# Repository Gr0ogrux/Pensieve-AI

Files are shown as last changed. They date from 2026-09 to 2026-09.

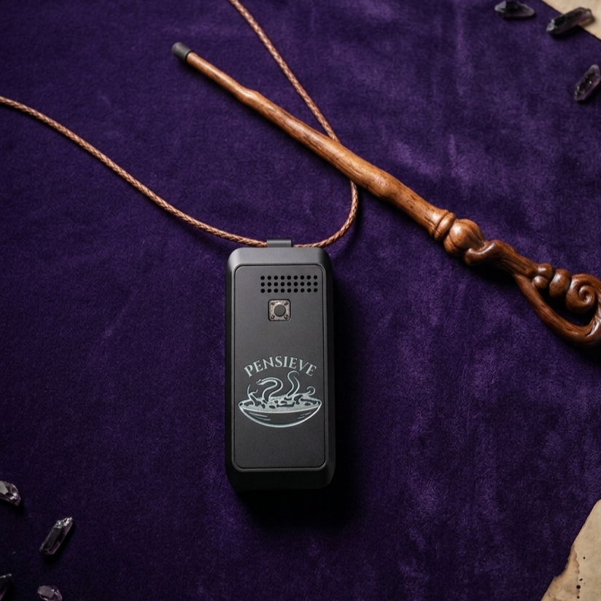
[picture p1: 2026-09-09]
images/pensieve_device.png

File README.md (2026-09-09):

pensieve_device

# **Pensieve AI** — a wearable voice assistant built from scratch

A push-to-talk pendant that records what you say, transcribes it locally,
figures out whether it's a reminder, calendar event, or just a note, and
files it into Google Calendar / Tasks automatically - no phone app, no
subscription, no cloud company's assistant, just a $30-ish pile of parts
and open firmware.

Press the button, say something, let go. That's the entire interaction.

## What it actually does

1. Records while the button is held (up to 60s), then stops
2. Saves to a microSD card - recordings are never lost even with no WiFi
3. Opportunistically syncs over WiFi whenever it's in range (on button
   press, or automatically once an hour even if you haven't used it)
4. A receiver script on a PC transcribes the audio locally (private,
   free - no audio ever leaves your network)
5. A small AI call classifies the transcript into an event / task / note
   and extracts the relevant details (dates, times, titles)
6. That gets pushed straight into Google Calendar or Google Tasks
7. Runs in deep sleep between uses for real multi-day battery life

## Why build this instead of buying one

Commercial AI pendants exist (Bee, Fieldy, etc.) but they're subscription
products with someone else's cloud in the middle. This is the same idea,
built from parts you can buy today, with the audio-to-transcript step
happening entirely on your own hardware, and the code fully open so you
can see (and change) exactly what it's doing with what you say.

## Hardware

| Part | Notes |
|---|---|
| Seeed XIAO ESP32-S3 Sense | The board - has the mic, camera (unused here), and microSD slot built in |
| LiPo battery, 3.7V, ~1000mAh, JST-PH1.25 connector | Solders directly to the board's BAT+/BAT- pads (no connector on the board itself) |
| Momentary tactile push button | 6x6mm style, 4-leg (2 electrical pairs) |
| 4x 4mm x 1mm neodymium magnets | Holds the case closed |
| Necklace cord | Threads through the printed bail |
| A 3D printer | PETG recommended for the final print, PLA fine for test-fitting |

Total cost is roughly $25-35 depending on where you source parts.

## Repo structure

- **`firmware/`** — the Arduino sketch that runs on the pendant itself
- **`case/`** — the 3D-printable case (parametric OpenSCAD source + ready-to-print STLs)
- **`server/`** — the Python script that runs on a PC, receives recordings, transcribes and classifies them, and creates the Calendar/Tasks entries
- **`docs/`** — supplementary notes (wiring, troubleshooting)

Each folder has its own README with setup specifics.

## Quick start

1. **Print the case** — see `case/README.md`
2. **Wire the button and battery** — see `docs/WIRING.md`
3. **Flash the firmware** — see `firmware/README.md`
4. **Set up the receiver** — see `server/README.md` (this is the more
   involved part: Python environment, a free Google Cloud project for
   Calendar/Tasks access, and a Gemini API key)
5. Press the button, say something, check your Google Tasks a few
   seconds later

## Known limitations / honest caveats

- **Battery life is genuinely limited by the ESP32-S3's always-on idle
  draw** if you don't use the deep-sleep firmware — expect closer to
  "charge nightly like a phone" than "charge weekly." The deep-sleep
  version in this repo addresses this, at the cost of a small delay
  (and possible clipped first syllable) each time you press the button,
  since the chip does a real reboot on every wake.
- **The XIAO ESP32-S3 has no dedicated JST battery connector** — only
  bare solder pads. Soldering directly to a LiPo is genuinely more
  dangerous than a plug-in connector; read `docs/WIRING.md` before
  attempting it.
- **This was built and debugged interactively over a single very long
  session**, including working through several real hardware/firmware
  interaction bugs (documented in `docs/` for anyone hitting the same
  walls). It works, but it's a hobbyist build, not a polished product.

## License

MIT — do whatever you want with this, attribution appreciated but not required.

---

*This project's code — firmware, case design, and server — was developed
with assistance from Google Gemini and Anthropic Claude.*

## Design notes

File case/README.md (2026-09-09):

# 3D Printed Case

`Pensieve AI.stl` is the ready-to-print export of the current wearable enclosure design, modeled in Tinkercad[cite: 1, 2].

## Design

- **Integrated alignment system:** Uses locating pins on the lid and mating holes on the base to ensure both halves line up squarely every time it snaps shut.
- **Magnetic latching:** Held closed with 3mm x 1mm neodymium disc magnets instead of screws, making battery checks and microSD access completely toolless[cite: 2].
- **Wearable bail:** Includes a solid integrated loop at the top end for a necklace cord or lanyard, keeping the pendant oriented face-forward rather than flipping around while worn[cite: 2].
- **Dedicated internal compartments:** An internal divider separates the board assembly from the battery compartment, holding each component securely to prevent internal rattles[cite: 2].
- **Acoustic and control cutouts:** Features an acoustic port aligned with the Sense daughterboard's PDM MEMS microphone capsule and dedicated clearances for the push button and USB-C port[cite: 2].

## Before printing

**Check your component dimensions first[cite: 2].** This enclosure was designed specifically around:
- Seeed Studio XIAO ESP32-S3 Sense[cite: 2]
- MakerHawk 803040 LiPo battery[cite: 2]
- 6x6mm tactile push button[cite: 2]
- 3mm x 1mm neodymium disc magnets

Tolerances are tuned around these specific physical parts[cite: 2]. If you use a different battery size or button style, you may need to import the STL into your CAD software to tweak internal clearances.

**Dry-fit everything before final assembly[cite: 2].** Test-fit the stacked XIAO board, battery, button, and magnets inside the shell[cite: 2]. Running a quick test print before final assembly ensures your printer’s calibration and shrinkage rates match the designed tolerances[cite: 2].

## Recommended print settings

- **Material:** PETG for the daily wearable version (more durable and temperature-resistant for everyday carry); PLA works well for rapid test prints[cite: 2].
- **Layer height:** 0.16–0.20 mm[cite: 2].
- **Walls / Perimeters:** 3 perimeters minimum (keeps the shell rigid under pocket or pendant use)[cite: 2].
- **Infill:** 15–20% (Gyroid or Grid)[cite: 2].
- **Supports:** None needed when oriented with the flat surfaces against the build plate[cite: 2].
- **Tolerances note:** PETG flows and flexes slightly differently than PLA, so test your pin-and-hole friction fit and magnet pockets after cooling[cite: 2].

## Magnet polarity

The STL file cannot encode magnet polarity[cite: 2]. Before applying superglue or epoxy into the magnet pockets, place a base magnet and lid magnet together to verify attraction[cite: 2]. If they repel, flip one side over before setting them into the recesses[cite: 2].

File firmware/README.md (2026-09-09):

# Firmware

`xiao_pendant_pushtotalk.ino` — the deep-sleep, push-to-talk version.
This is what actually runs on the pendant.

## Board setup (Arduino IDE)

1. Install the **"esp32" board package by Espressif Systems** via
   Boards Manager (not "Arduino ESP32 Boards" — there are two similarly
   named packages, you want Espressif's).
2. Select **Tools > Board > XIAO_ESP32S3**
3. Set **Tools > PSRAM > Enabled** (or "OPI PSRAM" depending on your
   core version) — required, the recording buffer lives in PSRAM
4. Upload speed of 921600 is fine (the default for this board)

## Before uploading

Open the sketch and fill in these three lines near the top:

```cpp
const char* WIFI_SSID     = "YOUR_WIFI_NAME";
const char* WIFI_PASSWORD = "YOUR_WIFI_PASSWORD";
const char* SERVER_URL    = "http://YOUR_PC_LOCAL_IP:5000/upload";
```

`SERVER_URL` is the local IP address of whichever PC is running the
receiver script (see `../server/`), found via `ipconfig` (Windows) or
`ifconfig`/`ip addr` (Mac/Linux). It has to be the PC's IP on your
*local* network (e.g. `192.168.1.x`), not a public address.

## How it behaves

- Press and hold the button (wired to pin D0) to record, release to stop
- Recordings longer than 60 seconds are automatically cut off (safety cap)
- Presses shorter than ~0.5s are discarded as accidental taps
- After recording, it tries to sync over WiFi (10s timeout) — if no
  WiFi is in range, the file just waits on the SD card and gets picked
  up on the next successful sync
- It also wakes up on its own once an hour to try syncing even without
  a button press
- Files that fail to upload twice are deleted automatically (almost
  always an accidental/garbage recording, not something worth
  retrying forever)
- Synced recordings are archived on the SD card and auto-deleted after
  7 days (configurable via `SENT_FILE_RETENTION_DAYS`)

## The deep sleep tradeoff (read this before you're confused by it)

This version puts the chip into deep sleep between actions rather than
staying fully awake — this is what gets you multi-day battery life
instead of roughly one day. The tradeoff: deep sleep is closer to a
full reboot than a pause. Every time it wakes (button press or hourly
timer), it's genuinely re-running `setup()` from scratch. That costs a
small delay before recording can start, and it's possible for the very
first instant of speech to be clipped while the mic finishes
initializing. If that's more annoying in practice than the battery
life is worth to you, an always-on (no deep sleep) version is a much
simpler modification — remove the `goToSleep()` call and the wake-cause
branching in `setup()`, and let `loop()` poll the button directly instead.

## Timezone

The NTP time sync (used for tracking how old archived files are)
defaults to US Eastern (`EST5EDT,M3.2.0,M11.1.0`). If you're elsewhere,
change the `TZ_STRING` constant — search "POSIX TZ string" for your
region's format.

## Wiring

See `../docs/WIRING.md` for the button and battery connections.

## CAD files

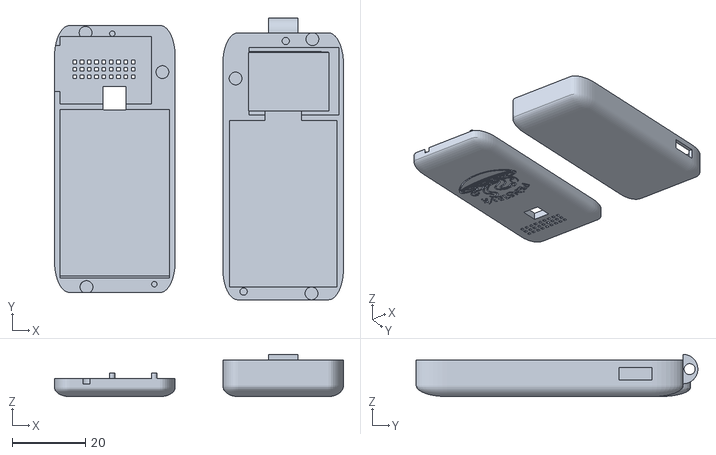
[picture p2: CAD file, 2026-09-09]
case/Pensieve AI.stl
79.0 x 77.0 x 11.5

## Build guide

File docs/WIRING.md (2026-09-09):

# Wiring

## Button

Wire one leg of the button to pin **D0** on the XIAO board, and the
other leg to any **GND** pin. No resistor needed — the firmware uses
the board's internal pull-up resistor.

Most small tactile buttons have 4 legs that are really just 2
electrical pairs (diagonal legs are connected to each other internally).
You only need one leg from each pair — check with a multimeter's
continuity mode if you're not sure which legs pair together.

## Battery

**The XIAO ESP32-S3 does not have a battery connector** — only two bare
solder pads on the underside of the board, labeled **BAT+** and
**BAT-** (small text, use a magnifying glass or your phone's camera
zoomed in to confirm you're reading them correctly).

This means either:
- Soldering a matching connector onto the pads (if your battery has a
  detachable connector and you have a matching part), or
- Soldering the battery's wires directly to the pads (permanent, but
  requires no extra parts)

### If soldering directly to the pads

This involves a LiPo battery, which is less forgiving of mistakes than
low-voltage signal wiring. A few things that matter here specifically,
not just generally good soldering practice:

1. **Identify polarity carefully.** Red is conventionally positive and
   black negative, but verify with a multimeter if you have one rather
   than assuming.
2. **If you need to cut the battery's existing wires** (e.g. to remove
   a connector that doesn't match anything you have), cut ONE wire at
   a time, not both together — cutting both simultaneously with a tool
   that spans both risks momentarily bridging positive and negative
   through the metal cutters, which is a real short-circuit risk on a
   LiPo cell.
3. **Double-check polarity again immediately before soldering** —
   positive wire to the pad marked +, negative to the pad marked -.
   Reversed polarity here can damage the board's charging circuit or
   the battery itself.
4. **Insulate both joints completely** (heat-shrink tubing or
   electrical tape) before final assembly — these joints will sit close
   to other components inside a sealed case, and an exposed short on a
   LiPo connection is a genuine fire/damage risk, not just "it won't work."
5. **Test power-up somewhere you can watch it** for the first minute or
   two (not inside the sealed case yet) — check for any unusual heat,
   smell, or the charge LED behaving normally.

Note: soldering directly to the pads means there's no way to fully
power the board off short of physically disconnecting a wire — it's
always live as long as the battery's connected. Not dangerous, just
worth knowing (the board will slowly drain the battery even sitting
idle, so give it an occasional charge if it goes unused for a while).

### Charging

Check your specific board's actual charge current before assuming a
number — it's been inconsistently documented in different places
(Seeed's wiki and datasheet have listed different figures for the same
board). At a conservative 50mA, a 1000mAh battery takes roughly 20-24
hours for a full charge from empty; budget accordingly rather than
expecting a quick top-up.

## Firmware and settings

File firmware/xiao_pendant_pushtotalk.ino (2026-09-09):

/*
 * XIAO ESP32-S3 Sense — "AI Pendant" recorder, DEEP SLEEP version
 *
 * Press and hold the button to record, release to stop (up to
 * MAX_RECORD_SECS as a safety cap). Between uses, the chip is in deep
 * sleep -- the lowest-power state available -- rather than sitting
 * fully awake waiting for a button press. It wakes on either:
 *   - the button being pressed, or
 *   - an hourly timer, to opportunistically sync over WiFi even if
 *     the button hasn't been touched
 *
 * IMPORTANT BEHAVIOR CHANGE FROM THE ALWAYS-ON VERSION:
 * Deep sleep is closer to a full power-off than a pause. Every wake
 * is a real reboot -- setup() runs again from scratch each time,
 * re-initializing the mic, SD card, etc. This costs a small amount of
 * time (typically a few hundred ms) before recording can actually
 * start, meaning the very first instant of speech right as you press
 * the button could be clipped while the chip finishes waking up. This
 * is the real tradeoff for the big battery life improvement -- worth
 * being aware of when you test it.
 *
 * WIRING: one leg of the button to pin D0, the other leg to any GND
 * pin on the board. No resistor needed -- we use the internal pull-up
 * (reconfigured for the RTC domain specifically before each sleep, so
 * it holds reliably while the chip is off).
 *
 * BEFORE UPLOADING:
 *   1. Fill in WIFI_SSID, WIFI_PASSWORD, SERVER_URL below.
 *   2. Tools > PSRAM > Enabled
 *   3. Tools > Board > XIAO_ESP32S3 (board package 2.0.14)
 */

#include "driver/i2s.h"
#include "driver/rtc_io.h"
#include "FS.h"
#include "SD.h"
#include <WiFi.h>
#include <HTTPClient.h>
#include "time.h"
#include "esp_sleep.h"

// ---- FILL THESE IN ----
const char* WIFI_SSID     = "YOUR_WIFI_NAME";
const char* WIFI_PASSWORD = "YOUR_WIFI_PASSWORD";
const char* SERVER_URL    = "http://YOUR_PC_LOCAL_IP:5000/upload"; // e.g. http://192.168.1.50:5000/upload
// ------------------------

#define SD_CS_PIN       21
#define I2S_MIC_CLK     42
#define I2S_MIC_DATA    41
#define SAMPLE_RATE     16000
#define MAX_RECORD_SECS 60      // safety cap -- recording stops here even if button stays held
#define I2S_PORT        I2S_NUM_0
#define BUTTON_PIN      1       // D0 on the XIAO -- other leg of button goes to GND -- confirmed RTC-capable on ESP32-S3
#define WIFI_TIMEOUT_MS 10000

// ---- Periodic sync + retention settings ----
const int SYNC_INTERVAL_SEC = 3600;               // wake on its own to sync at least this often
const int SENT_FILE_RETENTION_DAYS = 7;           // auto-delete archived recordings older than this
const int MAX_UPLOAD_ATTEMPTS = 2;                // give up and delete after this many failures --
                                                    // almost always an accidental button tap

// ---- NTP time (the board has no real-time clock of its own -- this is
// fetched over the network each time WiFi connects, so file ages can be
// tracked in real calendar days rather than just relative uptime) ----
const char* NTP_SERVER = "pool.ntp.org";
const char* TZ_STRING = "EST5EDT,M3.2.0,M11.1.0"; // US Eastern, handles DST automatically
bool g_timeIsValid = false;

// Survives deep sleep (unlike normal variables) -- purely a diagnostic
// counter so the Serial log shows how many wake cycles have happened.
RTC_DATA_ATTR int bootCount = 0;

uint8_t *g_fileBuf = nullptr;
const uint32_t MAX_SAMPLES = SAMPLE_RATE * MAX_RECORD_SECS;

void writeWavHeaderToBuf(uint8_t *header, uint32_t dataSize, uint32_t sampleRate) {
  uint32_t totalDataLen = dataSize + 36;
  uint32_t byteRate = sampleRate * 1 * sizeof(int16_t);
  header[0]='R'; header[1]='I'; header[2]='F'; header[3]='F';
  header[4]=(byte)(totalDataLen); header[5]=(byte)(totalDataLen>>8);
  header[6]=(byte)(totalDataLen>>16); header[7]=(byte)(totalDataLen>>24);
  header[8]='W'; header[9]='A'; header[10]='V'; header[11]='E';
  header[12]='f'; header[13]='m'; header[14]='t'; header[15]=' ';
  header[16]=16; header[17]=0; header[18]=0; header[19]=0;
  header[20]=1; header[21]=0;
  header[22]=1; header[23]=0;
  header[24]=(byte)(sampleRate); header[25]=(byte)(sampleRate>>8);
  header[26]=(byte)(sampleRate>>16); header[27]=(byte)(sampleRate>>24);
  header[28]=(byte)(byteRate); header[29]=(byte)(byteRate>>8);
  header[30]=(byte)(byteRate>>16); header[31]=(byte)(byteRate>>24);
  header[32]=2; header[33]=0;
  header[34]=16; header[35]=0;
  header[36]='d'; header[37]='a'; header[38]='t'; header[39]='a';
  header[40]=(byte)(dataSize); header[41]=(byte)(dataSize>>8);
  header[42]=(byte)(dataSize>>16); header[43]=(byte)(dataSize>>24);
}

uint32_t getNextCounter() {
  uint32_t n = 1;
  if (SD.exists("/counter.txt")) {
    File f = SD.open("/counter.txt", FILE_READ);
    if (f) { n = f.parseInt(); f.close(); }
  }
  File f = SD.open("/counter.txt", FILE_WRITE);
  if (f) { f.print(n + 1); f.close(); }
  return n;
}

bool uploadFile(const char* path) {
  File f = SD.open(path, FILE_READ);
  if (!f) return false;
  size_t size = f.size();
  uint8_t *buf = (uint8_t*) ps_malloc(size);
  if (!buf) { f.close(); return false; }
  f.read(buf, size);
  f.close();

  HTTPClient http;
  http.begin(SERVER_URL);
  http.setTimeout(20000);
  http.addHeader("Content-Type", "audio/wav");
  int code = http.POST(buf, size);
  free(buf);
  http.end();

  Serial.printf("  Upload %s -> HTTP %d\n", path, code);
  delay(300);
  return (code == 200);
}

bool syncNTPTime() {
  configTzTime(TZ_STRING, NTP_SERVER);
  struct tm timeinfo;
  if (getLocalTime(&timeinfo, 5000)) {
    Serial.printf("[+] Time synced: %04d-%02d-%02d %02d:%02d:%02d\n",
      timeinfo.tm_year + 1900, timeinfo.tm_mon + 1, timeinfo.tm_mday,
      timeinfo.tm_hour, timeinfo.tm_min, timeinfo.tm_sec);
    return true;
  }
  Serial.println("[!] NTP time sync failed -- skipping file-age cleanup this round.");
  return false;
}

void cleanupOldSentFiles() {
  if (!g_timeIsValid) return;

  time_t now = time(nullptr);
  const time_t maxAgeSecs = (time_t)SENT_FILE_RETENTION_DAYS * 24UL * 3600UL;

  File dir = SD.open("/recordings/sent");
  if (!dir) return;
  File entry;
  while ((entry = dir.openNextFile())) {
    if (!entry.isDirectory()) {
      String name = entry.name();
      entry.close();
      int sep = name.indexOf('_');
      if (sep > 0) {
        String epochStr = name.substring(0, sep);
        bool allDigits = epochStr.length() > 0;
        for (unsigned int i = 0; i < epochStr.length(); i++) {
          if (!isDigit(epochStr[i])) { allDigits = false; break; }
        }
        if (allDigits) {
          time_t fileTime = (time_t) epochStr.toInt();
          if (now - fileTime > maxAgeSecs) {
            String fullPath = String("/recordings/sent/") + name;
            if (SD.remove(fullPath)) {
              Serial.printf("[*] Deleted old archived file (%.1f days old): %s\n",
                (now - fileTime) / 86400.0, name.c_str());
            }
          }
        }
      }
    } else {
      entry.close();
    }
  }
  dir.close();
}

void syncPendingRecordings() {
  File dir = SD.open("/recordings");
  if (!dir) return;
  File entry;
  while ((entry = dir.openNextFile())) {
    if (!entry.isDirectory()) {
      String name = entry.name();
      String fullPath = String("/recordings/") + name;
      entry.close();

      int priorFailures = 0;
      int failMarker = name.indexOf("__fail");
      if (failMarker >= 0) {
        int dotPos = name.indexOf('.', failMarker);
        String countStr = name.substring(failMarker + 6, dotPos > 0 ? dotPos : name.length());
        priorFailures = countStr.toInt();
      }

      Serial.printf("[*] Syncing pending file: %s (prior failures: %d)\n", fullPath.c_str(), priorFailures);

      if (uploadFile(fullPath.c_str())) {
        String sentPath;
        if (g_timeIsValid) {
          sentPath = String("/recordings/sent/") + String((unsigned long)time(nullptr)) + "_" + name;
        } else {
          sentPath = String("/recordings/sent/") + name;
        }
        if (SD.rename(fullPath, sentPath)) {
          Serial.println("  -> uploaded and archived.");
        } else {
          Serial.println("  -> uploaded OK, but archiving failed. Removing local copy to prevent a duplicate re-upload.");
          SD.remove(fullPath);
        }
      } else {
        int newFailCount = priorFailures + 1;
        if (newFailCount >= MAX_UPLOAD_ATTEMPTS) {
          Serial.printf("  -> upload failed %d time(s), giving up and deleting.\n", newFailCount);
          SD.remove(fullPath);
        } else {
          String baseName = (failMarker >= 0) ? name.substring(0, failMarker) : name;
          String stem, ext;
          int dotIdx = baseName.lastIndexOf('.');
          if (dotIdx >= 0) {
            stem = baseName.substring(0, dotIdx);
            ext = baseName.substring(dotIdx);
          } else {
            stem = baseName;
            ext = "";
          }
          String newPath = String("/recordings/") + stem + "__fail" + String(newFailCount) + ext;
          SD.rename(fullPath, newPath);
          Serial.printf("  -> upload failed (attempt %d of %d), will retry next time.\n", newFailCount, MAX_UPLOAD_ATTEMPTS);
        }
      }
    } else {
      entry.close();
    }
  }
  dir.close();
}

bool initI2S() {
  i2s_config_t i2s_config = {
    .mode = (i2s_mode_t)(I2S_MODE_MASTER | I2S_MODE_RX | I2S_MODE_PDM),
    .sample_rate = SAMPLE_RATE,
    .bits_per_sample = I2S_BITS_PER_SAMPLE_16BIT,
    .channel_format = I2S_CHANNEL_FMT_ONLY_LEFT,
    .communication_format = I2S_COMM_FORMAT_STAND_I2S,
    .intr_alloc_flags = ESP_INTR_FLAG_LEVEL1,
    .dma_buf_count = 8,
    .dma_buf_len = 1024,
    .use_apll = false,
    .tx_desc_auto_clear = false,
    .fixed_mclk = 0
  };
  i2s_pin_config_t pin_config = {
    .bck_io_num = I2S_PIN_NO_CHANGE,
    .ws_io_num = I2S_MIC_CLK,
    .data_out_num = I2S_PIN_NO_CHANGE,
    .data_in_num = I2S_MIC_DATA
  };
  return (i2s_driver_install(I2S_PORT, &i2s_config, 0, NULL) == ESP_OK &&
          i2s_set_pin(I2S_PORT, &pin_config) == ESP_OK);
}

// Handles a full sync cycle: connects to WiFi, syncs real time via
// NTP, uploads anything pending, cleans up old archived files.
// Assumes I2S is NOT installed when called (either never started this
// wake cycle, or already torn down) -- unlike the always-on version,
// there's no need to restore the mic afterward since we're about to
// sleep either way.
void syncNow() {
  Serial.printf("[*] Trying WiFi (timeout %ds)...\n", WIFI_TIMEOUT_MS/1000);
  WiFi.mode(WIFI_STA);
  WiFi.begin(WIFI_SSID, WIFI_PASSWORD);
  uint32_t start = millis();
  while (WiFi.status() != WL_CONNECTED && millis() - start < WIFI_TIMEOUT_MS) {
    delay(300);
    Serial.print(".");
  }
  Serial.println();

  if (WiFi.status() == WL_CONNECTED) {
    Serial.printf("[+] WiFi connected (%s).\n", WiFi.localIP().toString().c_str());
    delay(500); // let the socket stack settle before a large transfer

    g_timeIsValid = syncNTPTime();

    Serial.println("[*] Syncing...");
    syncPendingRecordings();
    cleanupOldSentFiles();

    WiFi.disconnect(true);
  } else {
    Serial.printf("[!] WiFi failed. Status code: %d\n", WiFi.status());
    Serial.println("[!]   0=IDLE 1=NO_SSID_AVAIL 4=CONNECT_FAILED 6=DISCONNECTED");
    Serial.println("[*] No WiFi in range -- recording stays on SD, will sync later.");
  }
}

void recordAndSave() {
  int16_t *audioBuf = (int16_t *)(g_fileBuf + 44);
  uint32_t samplesGot = 0;
  size_t bytesRead = 0;

  Serial.println(">>> RECORDING (release button to stop) <<<");

  while (digitalRead(BUTTON_PIN) == LOW && samplesGot < MAX_SAMPLES) {
    size_t want = (MAX_SAMPLES - samplesGot) * sizeof(int16_t);
    if (want > 4096) want = 4096;
    esp_err_t res = i2s_read(I2S_PORT, (void*)(audioBuf + samplesGot), want, &bytesRead, pdMS_TO_TICKS(100));
    if (res == ESP_OK && bytesRead > 0) {
      samplesGot += bytesRead / sizeof(int16_t);
    }
  }

  float secs = (float)samplesGot / SAMPLE_RATE;
  Serial.printf("[+] Recording complete! %.1f seconds captured.\n", secs);

  // Done with the mic for this wake cycle -- free it before touching
  // WiFi, same lesson learned from the always-on version.
  i2s_driver_uninstall(I2S_PORT);

  if (samplesGot < SAMPLE_RATE / 2) {
    Serial.println("[*] Too short, discarding.");
    return;
  }

  uint32_t dataBytes = samplesGot * sizeof(int16_t);
  writeWavHeaderToBuf(g_fileBuf, dataBytes, SAMPLE_RATE);

  uint32_t n = getNextCounter();
  char path[40];
  snprintf(path, sizeof(path), "/recordings/rec%04u.wav", n);
  File audioFile = SD.open(path, FILE_WRITE);
  if (audioFile) {
    audioFile.write(g_fileBuf, dataBytes + 44);
    audioFile.close();
    Serial.printf("[+] Saved %s to SD card.\n", path);
  } else {
    Serial.println("[-] Failed to write file to SD!");
    return;
  }

  syncNow();
}

// Configures both wake sources and puts the chip into deep sleep.
// Never returns -- the next thing that happens is setup() running
// again from the top, as if the board had just been reset.
void goToSleep() {
  if (g_fileBuf) { free(g_fileBuf); g_fileBuf = nullptr; }

  // The regular pinMode(INPUT_PULLUP) pull-up only works while the
  // chip is awake. The RTC domain needs its own pull configuration to
  // hold the pin reliably HIGH while asleep, so a press produces a
  // clean LOW-going edge for the wake logic to catch.
  rtc_gpio_pullup_en((gpio_num_t)BUTTON_PIN);
  rtc_gpio_pulldown_dis((gpio_num_t)BUTTON_PIN);
  esp_sleep_enable_ext0_wakeup((gpio_num_t)BUTTON_PIN, 0); // wake on LOW (button pressed)
  esp_sleep_enable_timer_wakeup((uint64_t)SYNC_INTERVAL_SEC * 1000000ULL);

  Serial.printf("[*] Going to sleep. Will wake on button press or in %d minutes.\n", SYNC_INTERVAL_SEC / 60);
  Serial.flush();
  delay(50);
  esp_deep_sleep_start();
}

void setup() {
  unsigned long serialStart = millis();
  Serial.begin(115200);
  // Bounded wait, NOT "while(!Serial)" -- on battery alone with no USB
  // host attached, Serial never becomes true, and an unbounded wait
  // here would hang forever on every single wake cycle. This is the
  // one landmine that would otherwise make deep sleep useless for
  // real standalone (battery-only) operation.
  while (!Serial && millis() - serialStart < 2000) { delay(10); }

  esp_sleep_wakeup_cause_t wakeupReason = esp_sleep_get_wakeup_cause();
  bootCount++;

  Serial.println("\n--- AI Pendant: deep-sleep push-to-talk ---");
  Serial.printf("[*] Boot #%d, wakeup reason: %d\n", bootCount, (int)wakeupReason);
  Serial.println("[*]   0=power-on/reset  2=EXT0(button)  4=timer");

  pinMode(BUTTON_PIN, INPUT_PULLUP);

  if (SD.begin(SD_CS_PIN)) {
    if (!SD.exists("/recordings")) SD.mkdir("/recordings");
    if (!SD.exists("/recordings/sent")) SD.mkdir("/recordings/sent");
    Serial.println("[+] SD card ready.");

    if (wakeupReason == ESP_SLEEP_WAKEUP_EXT0) {
      Serial.println("[*] Woke up: button pressed.");
      g_fileBuf = (uint8_t *) ps_malloc(MAX_SAMPLES * sizeof(int16_t) + 44);
      if (!g_fileBuf) {
        Serial.println("[-] Failed to allocate recording buffer (check PSRAM enabled).");
      } else if (!initI2S()) {
        Serial.println("[-] I2S init failed!");
      } else {
        Serial.println("[+] Microphone ready.");
        recordAndSave(); // records, saves, and syncs -- all in one call
      }
    } else if (wakeupReason == ESP_SLEEP_WAKEUP_TIMER) {
      Serial.println("[*] Woke up: hourly timer.");
      syncNow();
    } else {
      Serial.println("[*] Fresh power-on (not from deep sleep). Doing an initial sync...");
      syncNow();
    }
  } else {
    Serial.println("[-] SD Mount Failed! Will retry next wake.");
  }

  goToSleep();
}

void loop() {
  // Never reached -- setup() always ends by calling esp_deep_sleep_start(),
  // which resets the chip rather than returning here. Arduino still
  // requires loop() to exist as a function.
}

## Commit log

2026-09-09 Revise README for updated case design details
    Updated the README to reflect changes in the wearable enclosure design, including new features, recommended print settings, and component checks.
2026-09-09 Delete case directory
    Re-uploading
    [Pensieve AI.stl, base_shell_v9.stl, lid_shell_v9.stl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]
2026-09-09 Add image of Pensieve device to README
    Added an image to the README for visual representation.
